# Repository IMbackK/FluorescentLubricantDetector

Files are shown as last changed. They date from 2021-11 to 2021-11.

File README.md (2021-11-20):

# Fluorescent lubricant detector

This is the hardware to a lubricant detection system that uses flurecent indecator materials to detect the thikness of lubricants on arbitrary surfaces.
It performs image detection and undistrotion of the surface under test, lighting and angle correction as well as the application of callibration curves to aquire accurate thikness data in a fast and non-contact fashion.

Hardware wise this is implemented using a integrating sphere to light an object under test evenly with a known irradiance and subsequently aquireing the surface of the object under test using a four cameras.

- The implentaton of the algorithums used can be found in this shared libary: https://gitlab.com/CKCSGLA/uvowunwrap
- The camera interface can be found here: https://gitlab.com/CKCSGLA/uvoscam
- A Gui frontend for this system can be found here: https://gitlab.com/CKCSGLA/LubricantThicknessMapper

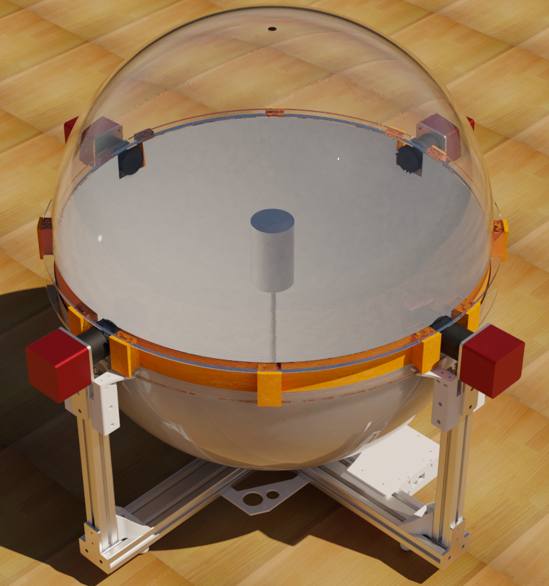
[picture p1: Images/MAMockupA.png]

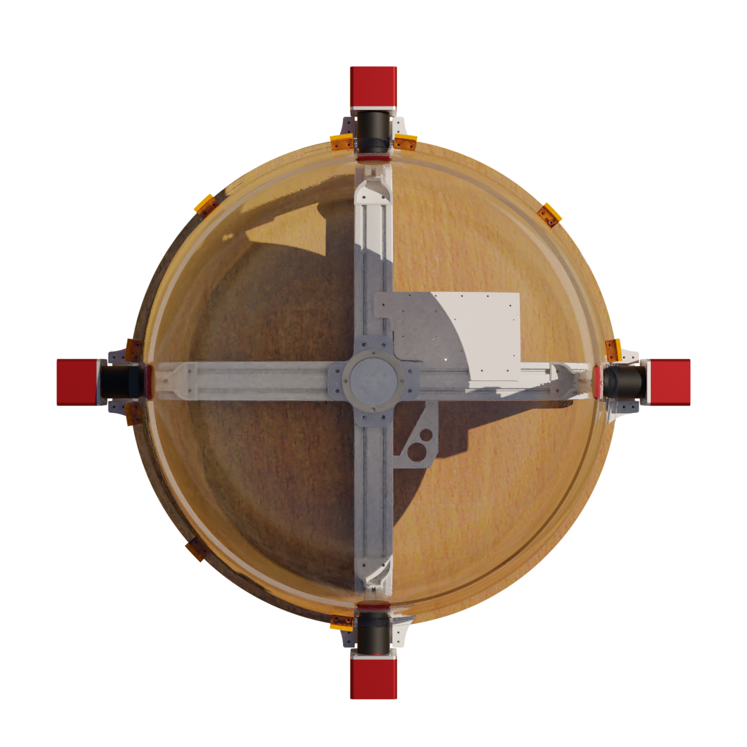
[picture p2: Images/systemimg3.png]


- The LedController directory contains the design of and the kicad files for a usb attached led contoller board with linear regulation and camera triggering.
	-  Kicad can be found here: https://www.kicad.org/
- The LedPcb directory contains the design of and the kicad files for a mechanical adapter board for the LED packages to be used with the LedController PCB.
- IntegratingSphere contains CAD fils for the mechanical setup of the integrating sphere and the assoicated equipment.

License: CC BY-SA 2.0, see https://creativecommons.org/licenses/by-sa/2.0/legalcode

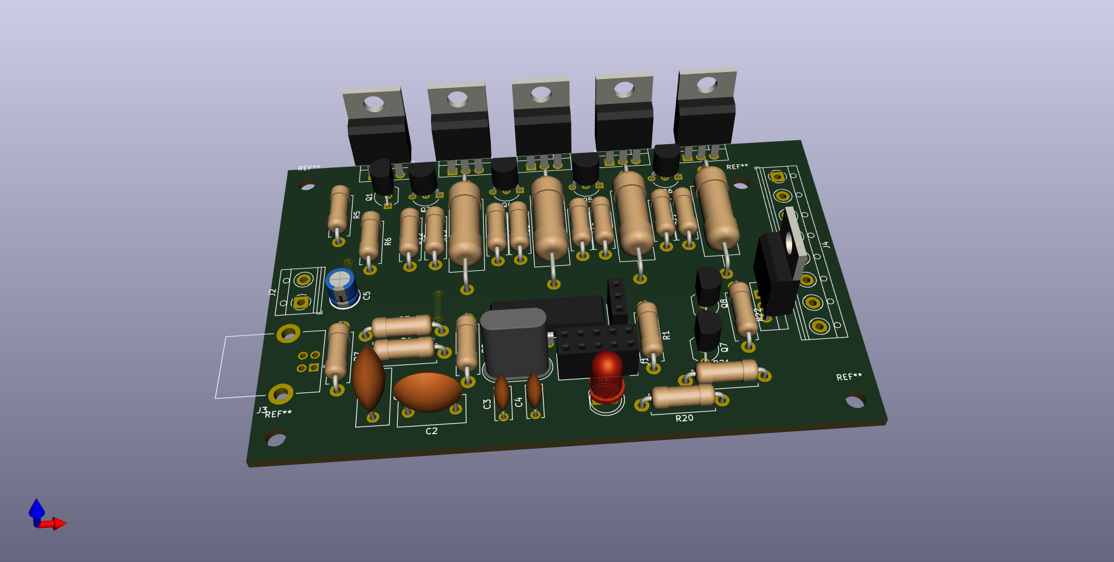
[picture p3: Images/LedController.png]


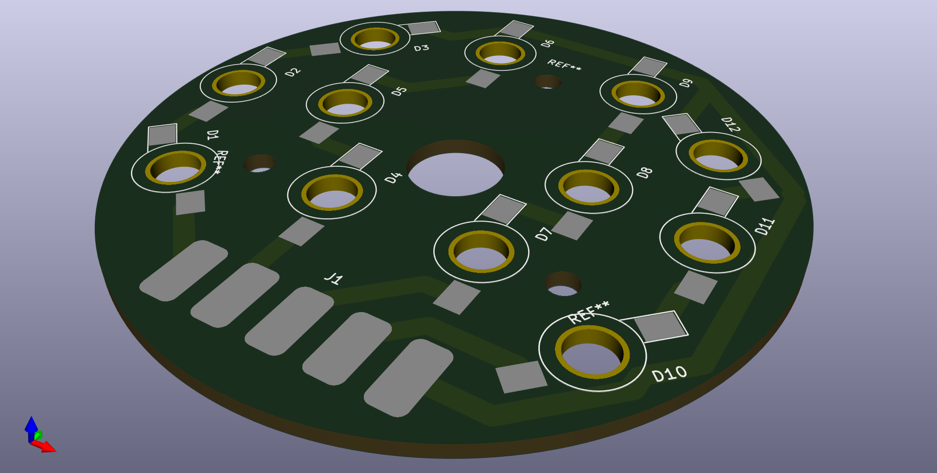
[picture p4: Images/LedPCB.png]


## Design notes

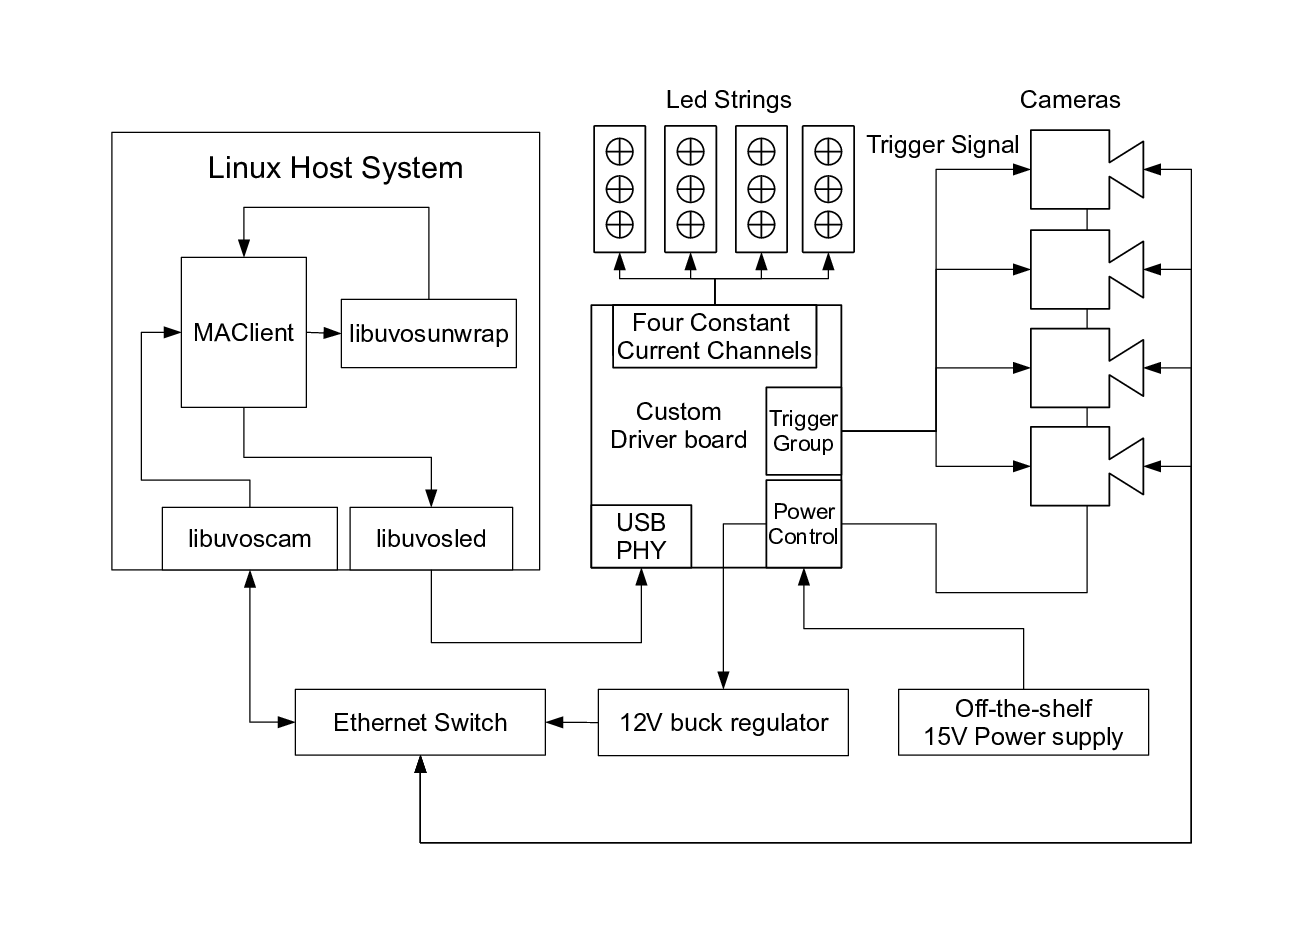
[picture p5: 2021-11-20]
Images/system.png

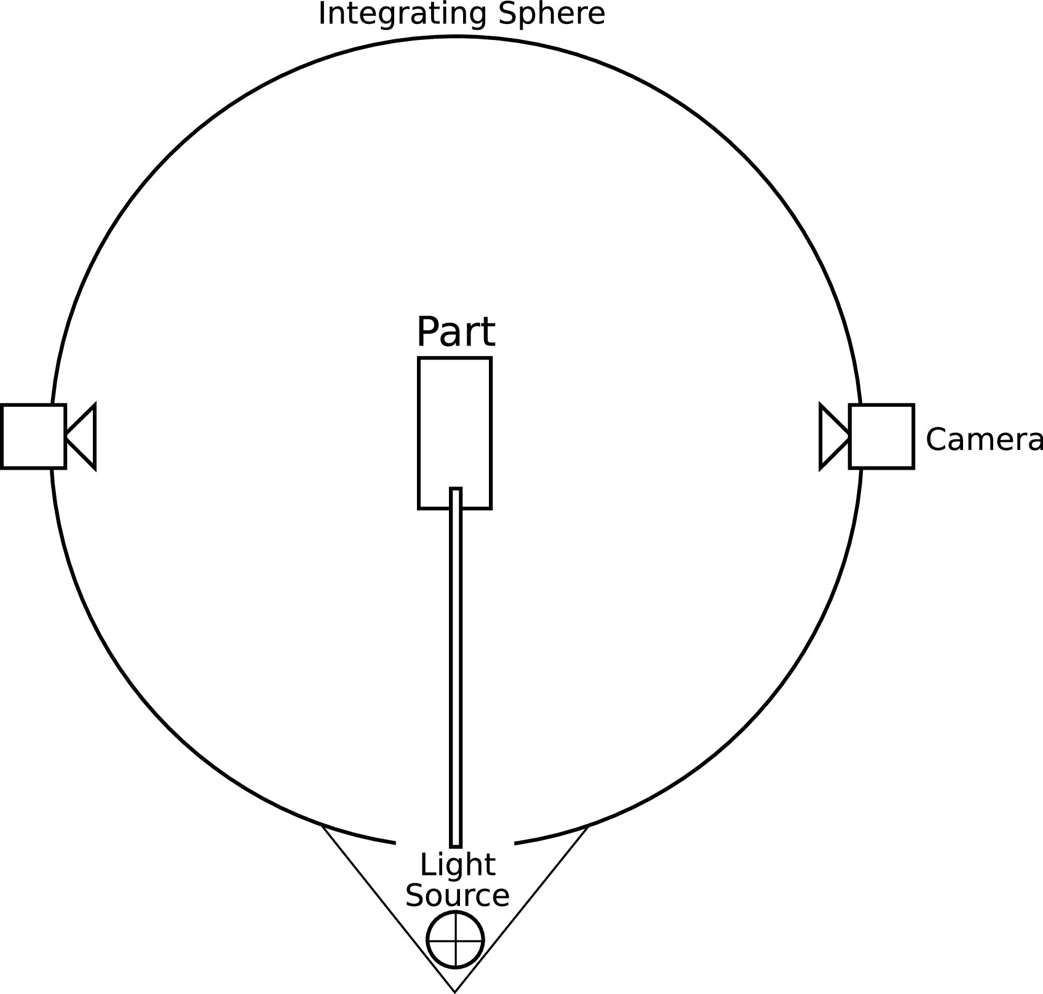
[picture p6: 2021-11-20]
Images/sphereSystem.png

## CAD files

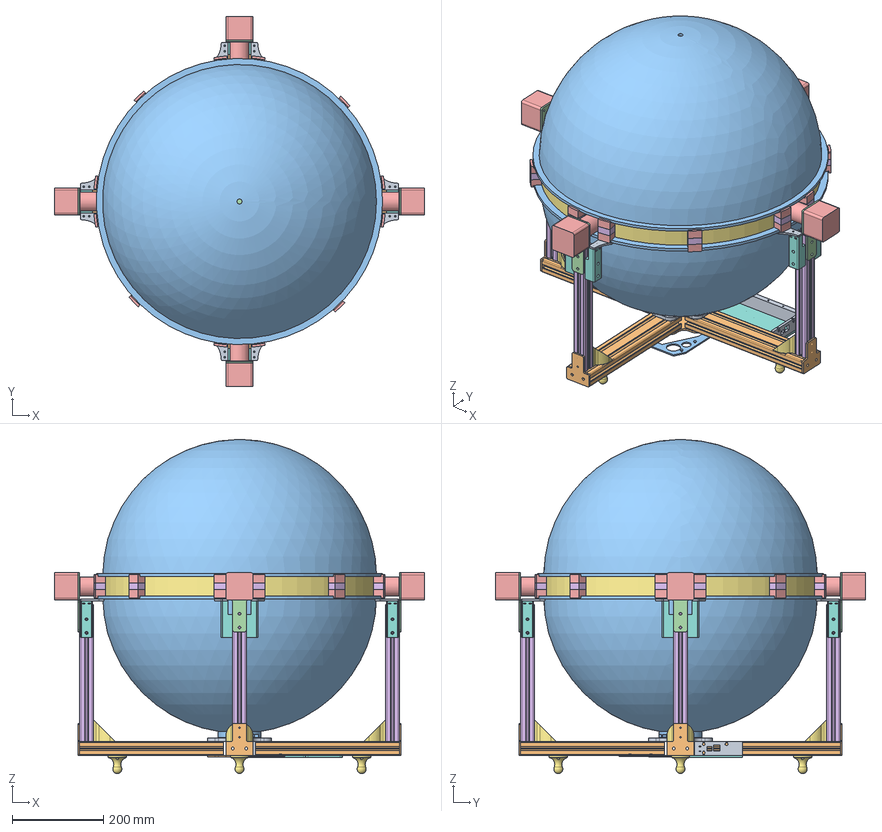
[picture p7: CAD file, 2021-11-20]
IntegratingSphere/Step/full.stp
810.2 x 810.2 x 731.4 mm
LCS_Origin x 22
LCS_0 x 95
LCS_1 x 93
LCS_2 x 74
LCS_3 x 33
LCS_4 x 5
LCS_5 x 5
LCS_6 x 5
LCS_7
LCS_8
LCS_9 x 5
LCS_10 x 5
Plane_1 x 4
Plane_2 x 4
LCS_2001
LCS_2002
LCS_2003
LCS_Origin001 x 4
LCS_Origin002 x 4
LCS_Origin003 x 4
DistPoints
aCircle
Radius

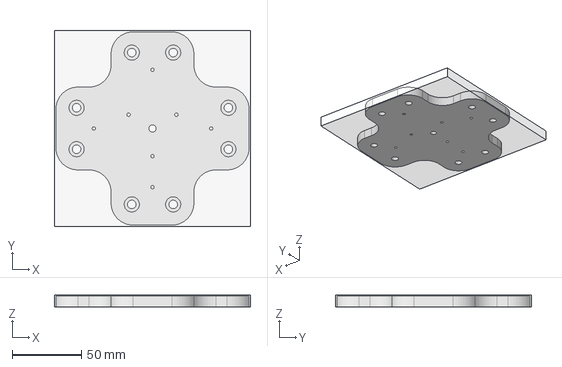
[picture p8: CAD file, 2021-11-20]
IntegratingSphere/FCStd/MainPlate.FCStd
142.0 x 142.0 x 9.00 mm
Stock

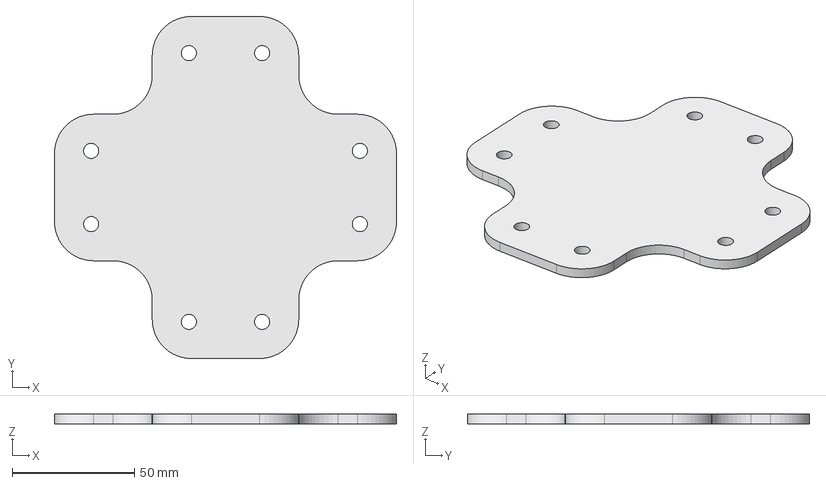
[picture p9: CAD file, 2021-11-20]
IntegratingSphere/FCStd/LowerMainPlate.FCStd
140.0 x 140.0 x 4.00 mm

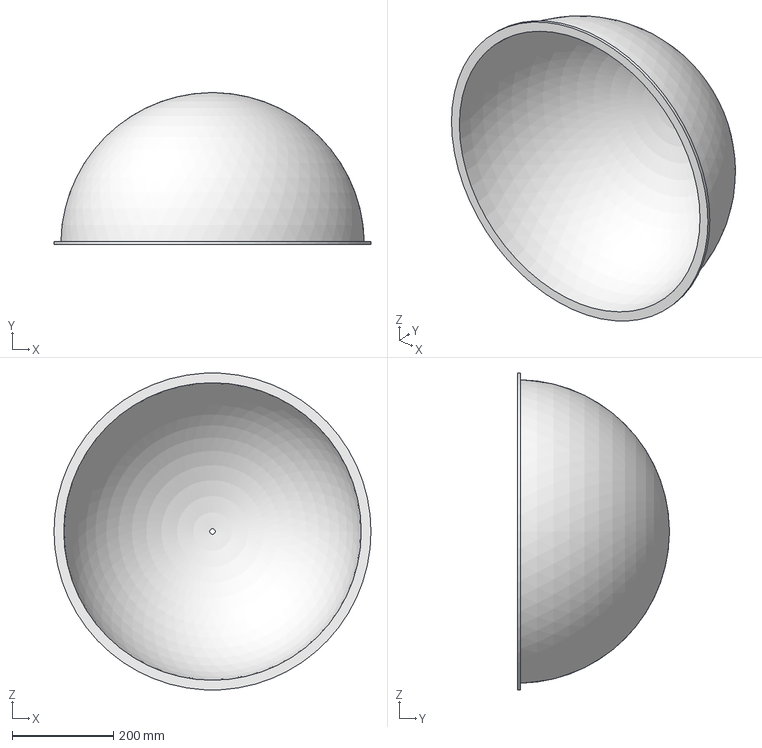
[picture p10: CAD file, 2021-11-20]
IntegratingSphere/FCStd/Hemesphere.FCStd
626.5 x 299.9 x 625.6 mm

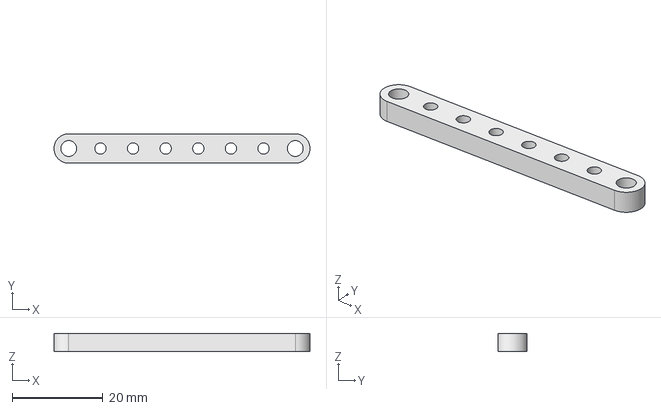
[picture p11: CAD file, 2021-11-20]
IntegratingSphere/FCStd/Busbar.FCStd
56.5 x 6.50 x 4.00 mm

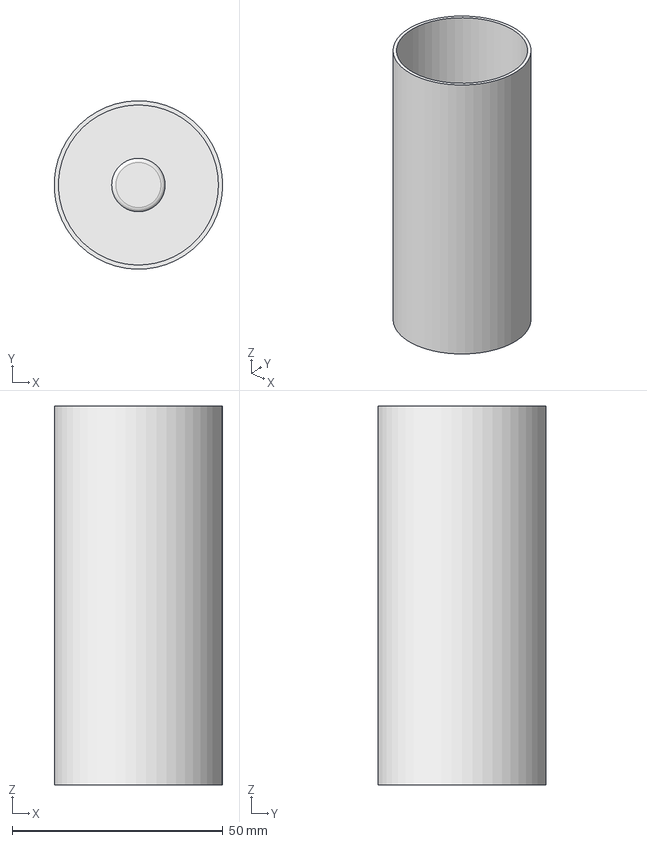
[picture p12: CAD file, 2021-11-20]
IntegratingSphere/FCStd/slug.FCStd
40.0 x 40.0 x 90.0 mm

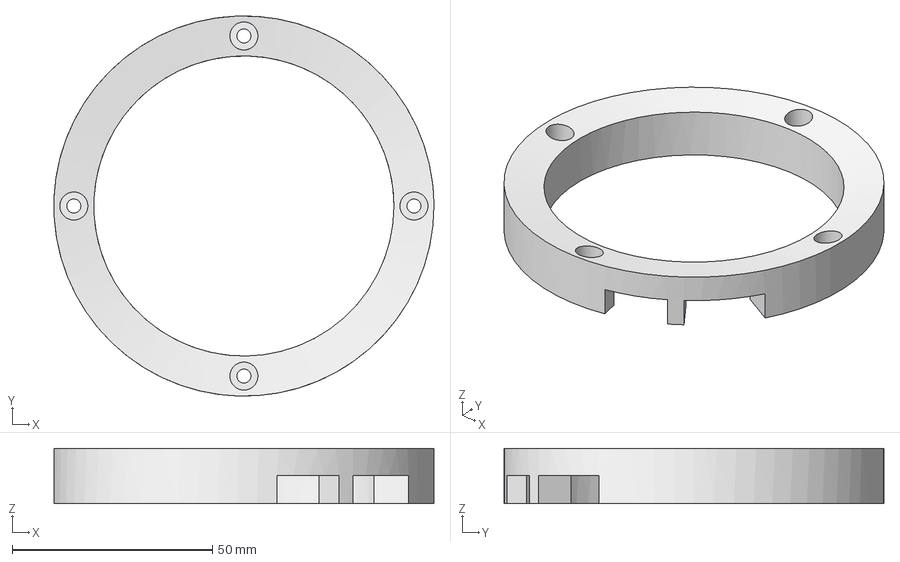
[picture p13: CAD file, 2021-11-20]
IntegratingSphere/FCStd/LowerHemHolder.FCStd
95.0 x 95.0 x 13.8 mm

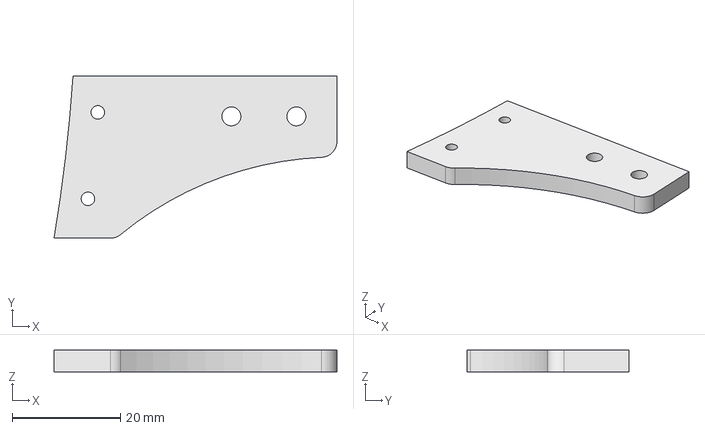
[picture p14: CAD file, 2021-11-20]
IntegratingSphere/FCStd/HorUpperHolder.FCStd
52.3 x 30.0 x 4.00 mm

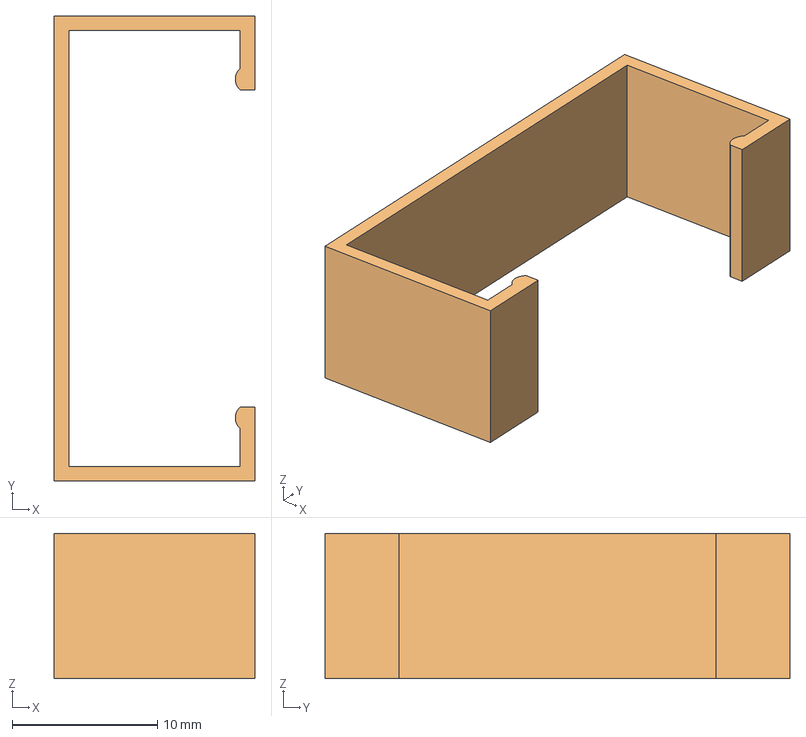
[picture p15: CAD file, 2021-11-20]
IntegratingSphere/FCStd/CableClamp.FCStd
13.8 x 32.0 x 10.0 mm

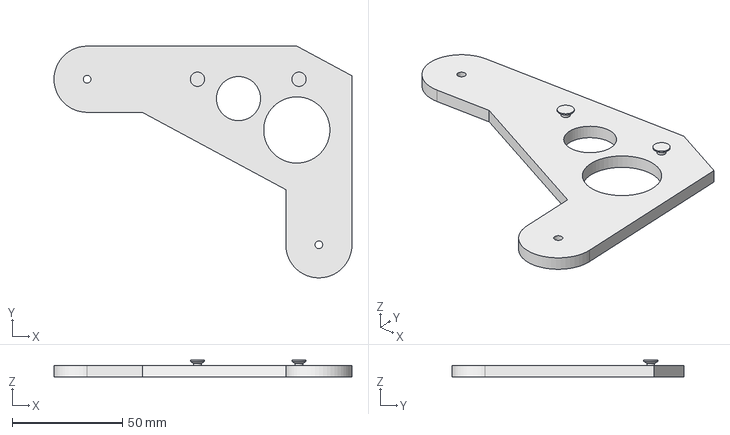
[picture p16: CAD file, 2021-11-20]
IntegratingSphere/FCStd/switchBracket.FCStd
135.0 x 105.0 x 7.50 mm

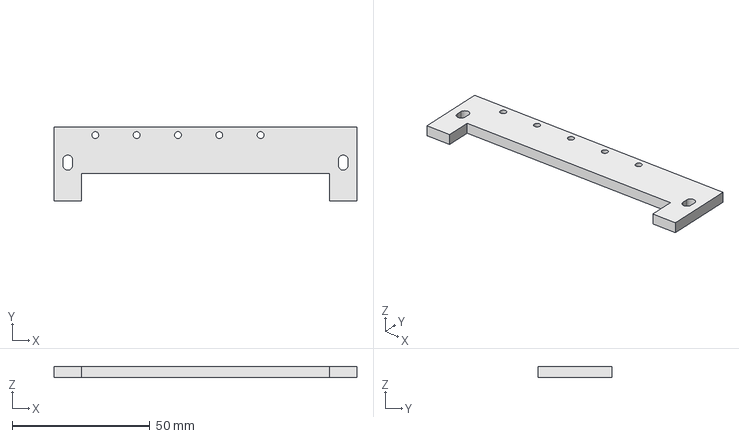
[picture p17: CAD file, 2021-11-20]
IntegratingSphere/FCStd/TermalBar.FCStd
110.0 x 27.0 x 4.00 mm

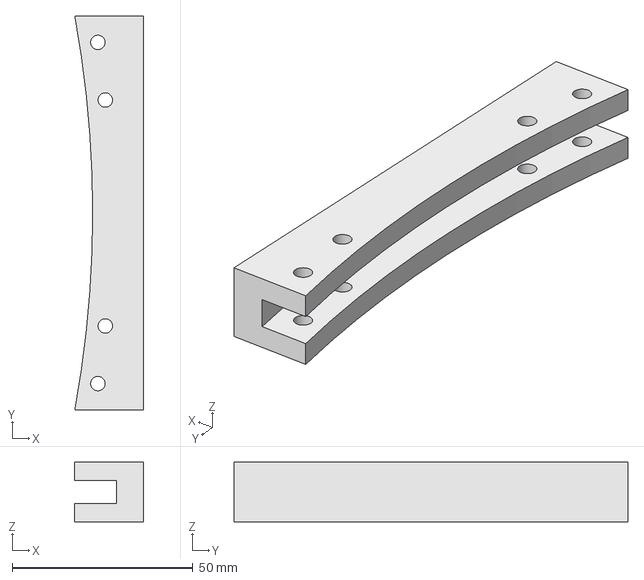
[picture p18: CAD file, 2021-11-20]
IntegratingSphere/FCStd/HorUpperHolderDrilJig.FCStd
19.0 x 109.0 x 16.5 mm

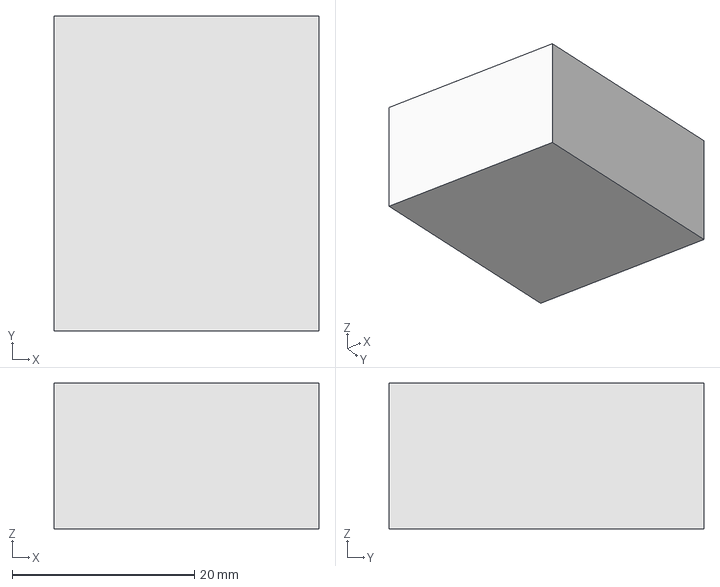
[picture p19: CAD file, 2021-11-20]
IntegratingSphere/FCStd/HemBlockB.FCStd
29.1 x 34.6 x 16.0 mm
Model-Body
Stock

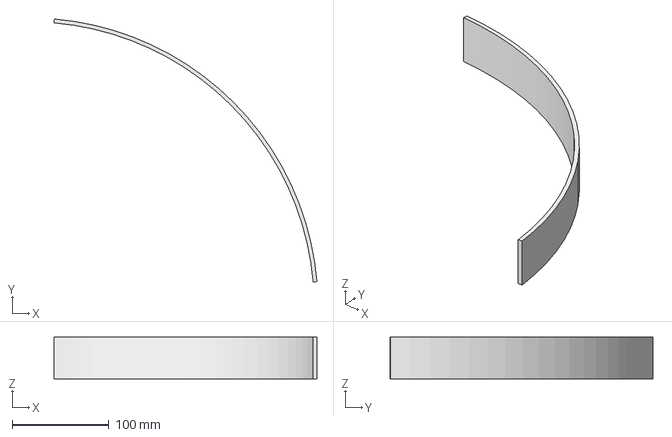
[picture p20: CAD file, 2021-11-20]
IntegratingSphere/FCStd/curveplate.FCStd
271.9 x 271.9 x 43.0 mm

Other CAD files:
IntegratingSphere/FCStd/as_interposer.FCStd
IntegratingSphere/FCStd/as_lower.FCStd
IntegratingSphere/FCStd/as_ma2.FCStd
IntegratingSphere/FCStd/Straightplate.FCStd
IntegratingSphere/FCStd/Baffel.FCStd
IntegratingSphere/FCStd/CameraMount.FCStd
IntegratingSphere/FCStd/CameraMountv2.FCStd
IntegratingSphere/FCStd/CameraStandin.FCStd
IntegratingSphere/FCStd/ChillPlate.FCStd
IntegratingSphere/FCStd/ChuckStandin.FCStd
IntegratingSphere/FCStd/ECaseFloor.FCStd
IntegratingSphere/FCStd/ECaseLID.FCStd
IntegratingSphere/FCStd/ECaseRiser.FCStd
IntegratingSphere/FCStd/EndPlate.FCStd
IntegratingSphere/FCStd/HemBlockA.FCStd
IntegratingSphere/FCStd/HorUpperHolderB.FCStd
IntegratingSphere/FCStd/LightMountWedge.FCStd
IntegratingSphere/FCStd/Post.FCStd
IntegratingSphere/FCStd/Profile30x60.FCStd
IntegratingSphere/FCStd/RingH.FCStd
IntegratingSphere/FCStd/RingL.FCStd
IntegratingSphere/FCStd/as_HemBlock.FCStd
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

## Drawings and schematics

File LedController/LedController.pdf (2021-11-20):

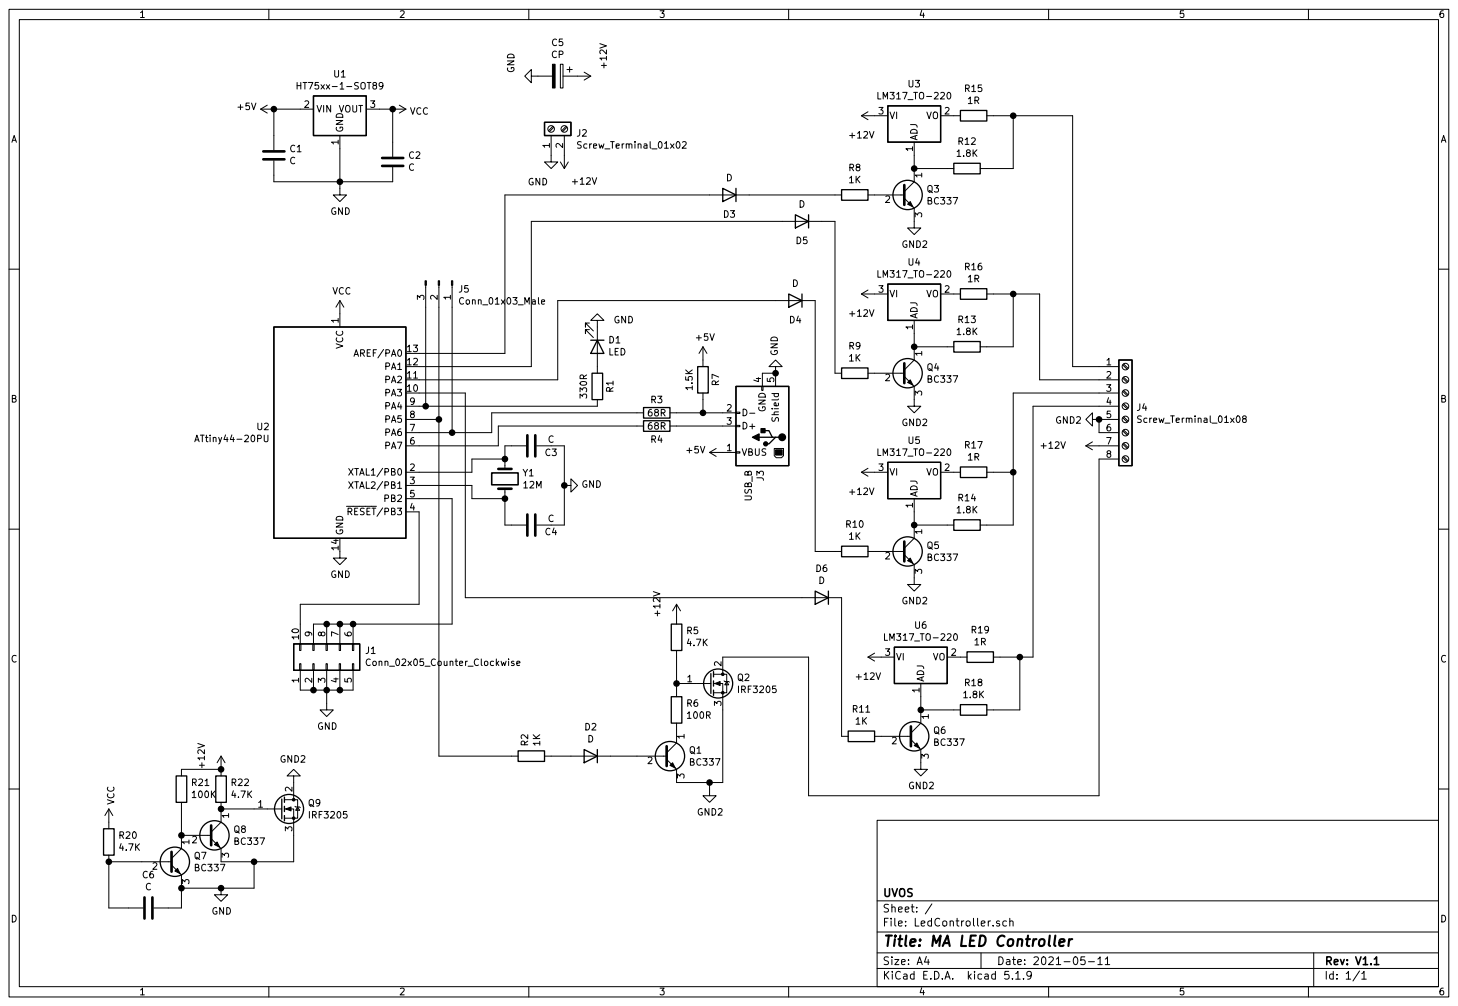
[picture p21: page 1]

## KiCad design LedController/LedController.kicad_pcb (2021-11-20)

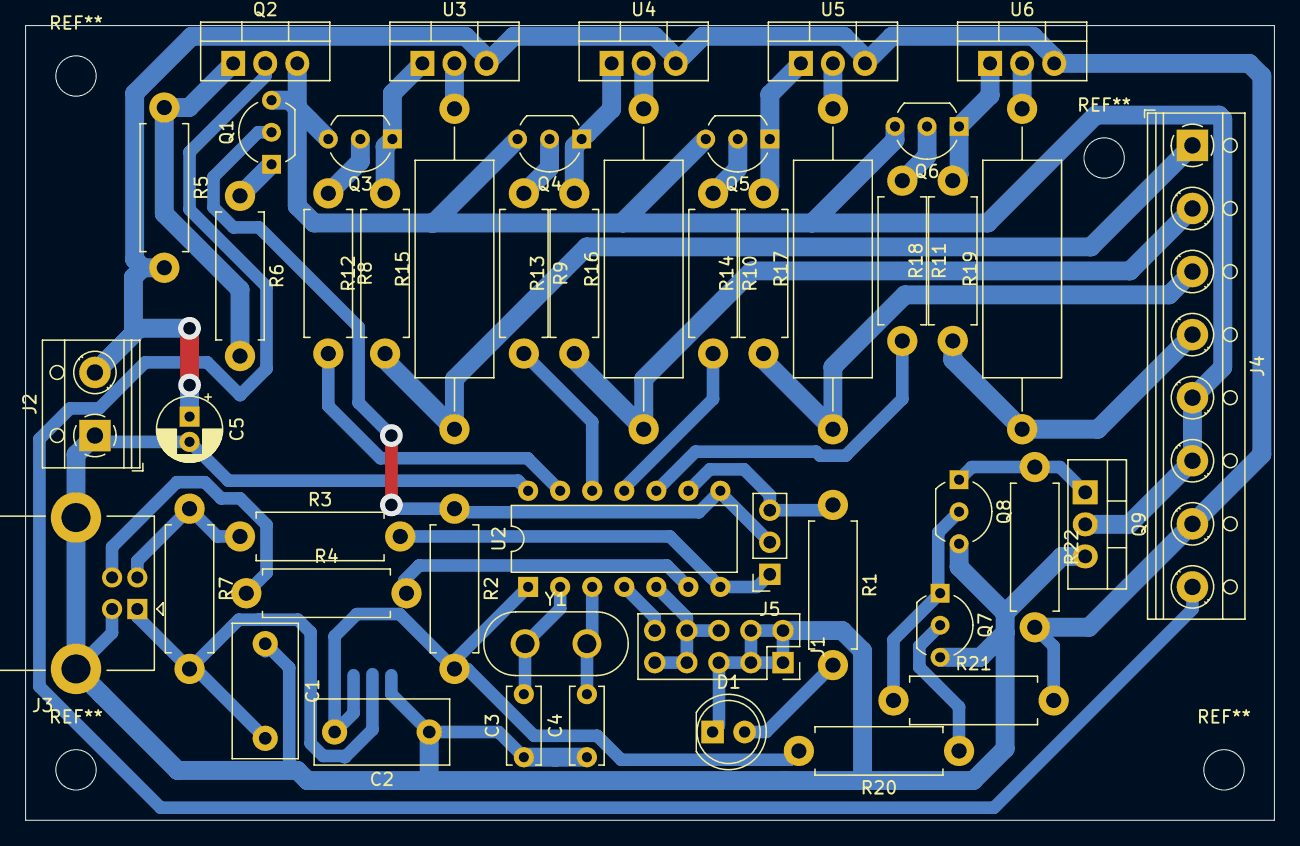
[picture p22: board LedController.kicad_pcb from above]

Board: 2 copper layers, 99.0 x 63.0 mm, 49 parts (1 on the bottom side), 42 nets.

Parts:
C1, C2: C; C_Disc_D10.5mm_W5.0mm_P7.50mm
C3, C4: C; C_Disc_D6.0mm_W2.5mm_P5.00mm
C5: CP; CP_Radial_D5.0mm_P2.00mm
D1: LED; LED_D5.0mm
J1: Conn_02x05; PinSocket_2x05_P2.54mm_Vertical
J2: Screw_Terminal_01x02; TerminalBlock_RND_205-00012_1x02_P5.00mm_Horizontal
J3: USB_B; USB_B_Lumberg_2411_02_Horizontal
J4: Screw_Terminal_01x08; TerminalBlock_RND_205-00018_1x08_P5.00mm_Horizontal
J5: Conn_01x03_Male; PinSocket_1x03_P2.54mm_Vertical
Q1, Q3, Q4, Q5, Q6, Q7, Q8: BC337; TO-92_Inline_Wide
Q2, Q9: IRF3205; TO-220-3_Vertical
R1: 330R; R_Axial_DIN0411_L9.9mm_D3.6mm_P12.70mm_Horizontal
R2, R8, R9, R10, R11: 1K; R_Axial_DIN0411_L9.9mm_D3.6mm_P12.70mm_Horizontal
R3, R4: 68R; R_Axial_DIN0411_L9.9mm_D3.6mm_P12.70mm_Horizontal
R5, R20, R22: 4.7K; R_Axial_DIN0411_L9.9mm_D3.6mm_P12.70mm_Horizontal
R6: 100R; R_Axial_DIN0411_L9.9mm_D3.6mm_P12.70mm_Horizontal
R7: 1.5K; R_Axial_DIN0411_L9.9mm_D3.6mm_P12.70mm_Horizontal
R12, R13, R14, R18: 1.8K; R_Axial_DIN0411_L9.9mm_D3.6mm_P12.70mm_Horizontal
R15, R16, R17, R19: 1R; R_Axial_DIN0617_L17.0mm_D6.0mm_P25.40mm_Horizontal
R21: 100K; R_Axial_DIN0411_L9.9mm_D3.6mm_P12.70mm_Horizontal
U1: HT75xx-1-SOT89; SOT-89-3
U2: ATtiny44-20PU; DIP-14_W7.62mm
U3, U4, U5, U6: LM317_TO-220; TO-220-3_Vertical
Y1: 12M; Crystal_HC50_Vertical

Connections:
+5V: C1.2, J3.1, R7.2, U1.2
+12V: C5.1, J2.2, J4.7, R5.2, R21.2, R22.2, U3.3, U4.3, U5.3, U6.3
GND: C1.1, C2.1, C3.1, C4.1, C5.2, D1.1, J1.1, J1.2, J1.3, J1.4, J1.5, J2.1, J3.4, J3.5, Q7.3, Q8.3, Q9.3, U1.1, U2.14
GND2: J4.5, J4.6, Q1.3, Q2.3, Q3.3, Q4.3, Q5.3, Q6.3, Q9.2
unnamed: C3.2, U2.2, Y1.1
unnamed: C4.2, U2.3, Y1.2
unnamed: D1.2, R1.2
unnamed: J1.6, J1.7, J1.8, J1.9, U2.5
unnamed: J1.10, U2.4
unnamed: J3.2, R3.1, R7.1
unnamed: J3.3, R4.1
unnamed: J4.1, R12.1, R15.1
unnamed: J4.2, R13.1, R16.1
unnamed: J4.3, R14.1, R17.1
unnamed: J4.4, R18.1, R19.1
unnamed: J4.8, Q2.2
unnamed: J5.1, R3.2, U2.7
unnamed: J5.2, Q1.2, R2.1, U2.8
unnamed: J5.3, R1.1, U2.9
unnamed: Q1.1, R6.1
unnamed: Q2.1, R5.1, R6.2
unnamed: Q3.1, R12.2, U3.1
unnamed: Q3.2, R8.1
unnamed: Q4.1, R13.2, U4.1
unnamed: Q4.2, R9.1
unnamed: Q5.1, R14.2, U5.1
unnamed: Q5.2, R10.1
unnamed: Q6.1, R18.2, U6.1
unnamed: Q6.2, R11.1
unnamed: Q7.1, Q8.2, R21.1
unnamed: Q7.2, R20.1
unnamed: Q8.1, Q9.1, R22.1
unnamed: R4.2, U2.6
unnamed: R8.2, U2.13
unnamed: R9.2, U2.12
unnamed: R10.2, U2.11
unnamed: R11.2, U2.10
unnamed: R15.2, U3.2
unnamed: R16.2, U4.2
unnamed: R17.2, U5.2
unnamed: R19.2, U6.2
VCC: C2.2, R2.2, R20.2, U1.3, U2.1

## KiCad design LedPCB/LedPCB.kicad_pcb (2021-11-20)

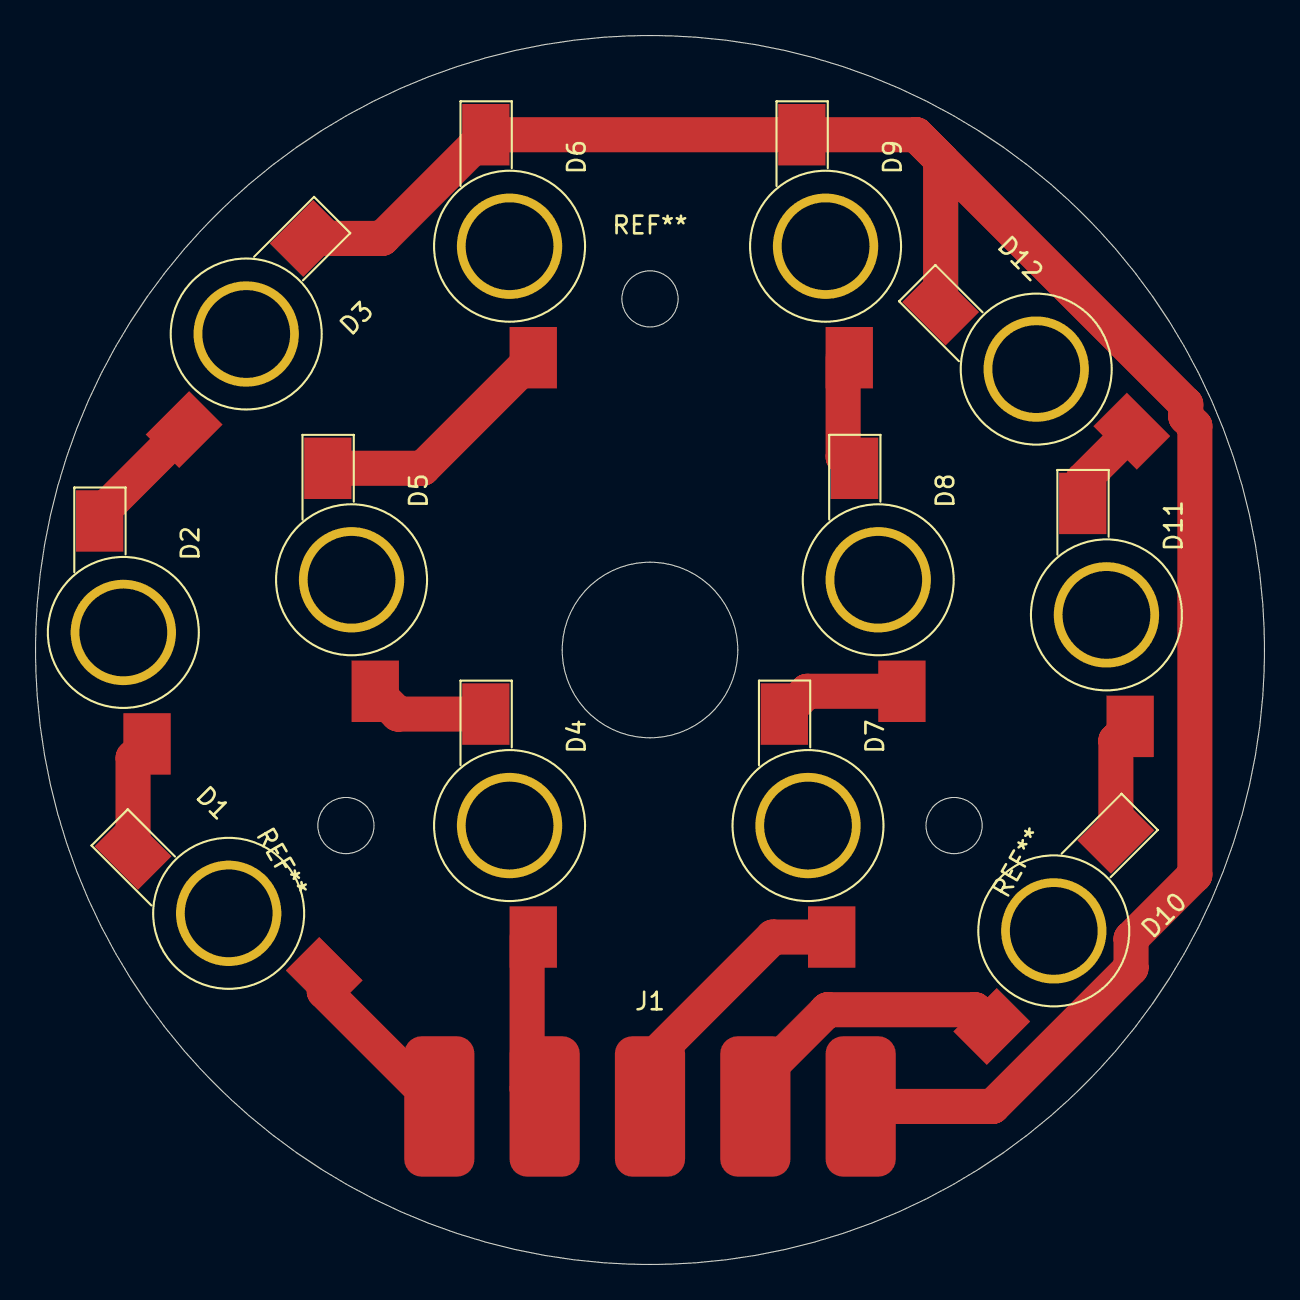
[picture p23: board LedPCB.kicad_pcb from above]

Board: 2 copper layers, 70.0 x 70.0 mm, 13 parts (0 on the bottom side), 13 nets.

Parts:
D1, D2, D3, D4, D5, D6, D7, D8, D9, D10, D11, D12: LED; LED_1W_3W_R8_hole
J1: Conn_01x05_Male; WireSolderingPad5

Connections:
GND: D3.1, D6.1, D9.1, D12.1, J1.1
unnamed: D1.1, D2.2
unnamed: D1.2, J1.5
unnamed: D2.1, D3.2
unnamed: D4.1, D5.2
unnamed: D4.2, J1.4
unnamed: D5.1, D6.2
unnamed: D7.1, D8.2
unnamed: D7.2, J1.3
unnamed: D8.1, D9.2
unnamed: D10.1, D11.2
unnamed: D10.2, J1.2
unnamed: D11.1, D12.2
